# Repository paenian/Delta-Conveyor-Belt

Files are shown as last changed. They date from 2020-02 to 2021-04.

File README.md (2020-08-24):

## Delta-Conveyor-Belt
Adding a conveyor belt to my delta printer for part ejection.  The deltabot is somewhat described here: [Bertha](https://github.com/paenian/bertha), however it's been upgraded to the Delta Smart Effector as part of the conveyor belt addon.

Bertha Overview: https://www.youtube.com/watch?v=_Ud6TqBTL1Y

This is a follow-up to [Beltalowda](https://github.com/paenian/beltalowda),  which was styled as an upgraded Printrbelt.

## Status!
Bertha is quite reliable and functioned well printing face shields to help fight the COVID pandemic - check out her timelapse: https://www.youtube.com/watch?v=ywWMOnBR8Mk

## Expanding the Belt!

I've been expanding the belt system, however - there are versions for:
- [Kossel 3D printer](https://github.com/paenian/Delta-Conveyor-Belt/tree/master/kossel%20-%20240mm%20triangle) - this works well, but is small :-)
- [Prusa Mini](https://github.com/paenian/Delta-Conveyor-Belt/tree/master/prusa%20mini) - Working, more actively developing around this machine right now.

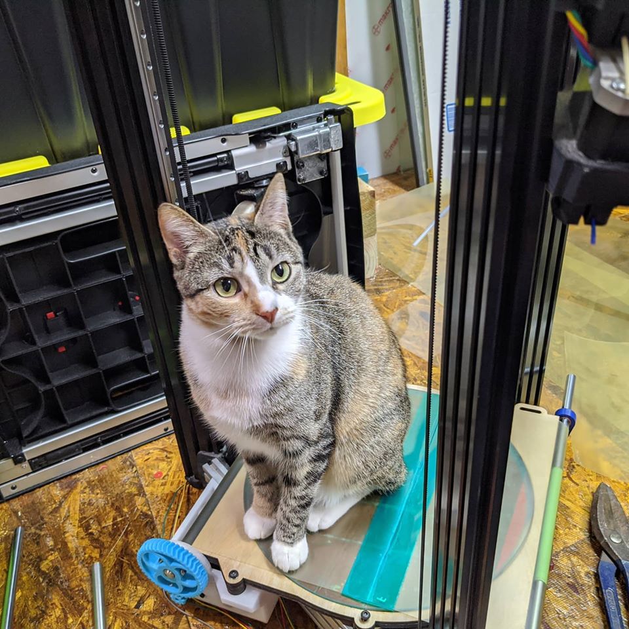
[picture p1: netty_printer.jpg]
Netty is the official mascot


### I've seen other belt printers... how is yours different?
I started working with stainless steel belts on Beltalowda (based off of the Printrbot's Printrbelt - the [White Knight](https://3ddistributed.com/white-knight-3d-printer/) uses steel as well) but was not super happy with it.  For one, the belt is inflexible - so it requires large rollers and very high force to stretch it out flat.  The other issue is heating the belt - as the belt material expands, it develops ripples in the surface ruining your print's bottom layer.  This is also an issue when the nozzle gets close to the bed - without excellent cooling, the bed will locally warp due to local heating from the nozzle and hot plastic.

To get around those, I experimented with thin, plastic belts - PEI, Kapton and Polyester (duralar).  They can be bent around a tiny radius, stretch minimally, and have managable thermal expansion.  To combat local heating, and help your print stick - heat the bed first!  To combat the warping that heating the bed gets you, I'm heating both sides of the bed - and rolling it to flatten it out when hot.  This has mitigated the problem enough that I've had successful prints, but plastics that warp (ABS) locally bend the belt to their will.  This can be partially solved with rafts, but given how well the thin belts are working, I thought I should release to the community and see what other solutions crop up.  I believe simply tuning the temperature and rolling profiles can lead to some improvement.

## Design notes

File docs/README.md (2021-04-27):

# Welcome to PrintShift!

This site was created using [**Docsify**](https://docsify.js.org), which is an open source documentation site generator, and imported in GitHub pages.

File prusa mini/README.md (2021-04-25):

#  Prusa Mini Conveyor Belt!

Status: Fully Functional!

Quick overview - this repo contains all the files I used to add a conveyor belt to my Prusa Mini.

## BELT MATERIAL
The current belt is made from .2mm thick Kapton, ordered from AliExpress and lasercut.  You can totally hand-cut it, but tracking of the belt is a bit of a pain.

The belt is designed to be easily replaced - other materials I have used:
 * .01" polyester film: Cuts easily, prints stick very well with hairspray.  This belt has higher thermal expansion, but with PLA or lower temps on the heater it works great, and is quite cheap.
  * https://www.mcmaster.com/8567K92/
  * Use hairspray to help prints stick.
 * .225mm Kapton: Hard to cut, especially by hand - recommend using a laser.  Low thermal expansion.  More expensive than the polyester.
  * https://www.aliexpress.com/item/4000699107361.html?spm=a2g0s.9042311.0.0.19534c4dqCLd9z
  * Use hairspray to help prints stick.
 * .005" ULTEM/PEI film: Prints stick well, but it's too flexible.  After ~10 hours printing, sheet sheared while printing.  It was under a lot of tension.  Gets expensive quick.
  * https://catalog.cshyde.com/item/films/ultem-pei-polyethermide-resin/36-5f
 * .01" ULTEM/PEI film: Same story as the .005; less flexible, of course, so prints warped less on it.  However, it did shear mid-print after maybe 100 hours of printing - it lasted longer, but split right in two.  My assumption is more due to fatigue from all the rolling.
  * https://catalog.cshyde.com/item/films/ultem-pei-polyethermide-resin/36-10f
  
 I have used thicker and stiffer belts, too - various stainless steels and conveyor materials, usually covering the belt itself in PET tape to get good adhesion and release.  However, these require larger, stronger rollers - so aren't compatible with the printers in this repository.

## CONTROL
The belt is controlled by a microswitch mounted on the top of the Z axis.  When the Z gets high enough and Y is forward enough, your parts scoot.  The nice part is no modification of the firmware is required - just some special start and end GCODE in your slicer.  I do take power for the motor from inside the Prusa Mini box for neatness - I like my printers as self-contained as possible.

The other modifications to the Prusa Mini involve raising the bed 4mm - so combined with the switch up top, you're losing about 15mm of usable Z axis.

Right now, the belt is 150mm in width - so your Y axis shrinks a bit when printing on the belt.  You can, however, still print using the entire bed - just put the metal build plate on top of the belt!  I plan to work on widening the belt, but for now I want the machine to be as rigid as possible.

## PARTS NEEDED
.2mm thick KAPTON film - 155mm by 425-430mm
 - Alternative bed material is PEI film or Dur-a-lar

5/16" diameter tool steel rod, for the rollers
5/16" ID EPDM rubber tubing, goes on the drive rod to grip and move the belt

V-156-1C25 microswitch to actuate the belt - https://smile.amazon.com/Cylewet-V-155-1C25-Switch-Arduino-CYT1081/dp/B075PTBML8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

24v, 30rpm , 6mm worm gear motor to drive the belt: https://smile.amazon.com/gp/product/B01N1JQLG4/ref=ppx_yo_dt_b_asin_title_o00_s00?ie=UTF8&psc=1

various screws and wires
10mm long M3 hex standoffs: https://www.mcmaster.com/94868A166/

##INSTALLATION
For all the printed parts, I used PETG with carbon-fiber embedded.  Not all need the strength, but I'd say the gears and the LM8UU clamps definitely benefit.

First dismantle the heated bed and set aside - then take the entire Y axis apart.  The belt needs to run flat, so first we replace the U-bolt clamps holding the LM8UUs on with printed clamps.
 - I used a chamfer drill to make countersink holes in the aluminum Y carriage, and used M3x16mm flat top screws.  Clearance is pretty tight on the electronics side.
 - Printed Part: lm8uu clamp.stl
While you're down here, remove all the hexagonal standoffs.  We need taller ones.

Replace the front three and back three hex standoffs with 10mm long ones - middle standoffs never get replaced.

Netty is the official mascot

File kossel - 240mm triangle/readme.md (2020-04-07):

Kossel Conveyor Belt!

These are all the STLs you need to throw a belt on the bottom of a Kossel 3D printer.

Parts Required:
 * (1)  200 by 213mm by 3mm borosilicate glass plate - a rectilinear prism, not round glass!
 * (1)  200mm silicone heater pad - should be ~2mm thick.  It's gotta be placed nice and central.
 * (1)  250mm 1/2" steel shaft - this is the idler
 * (1)  300mm 1/2" steel shaft - this is the drive roller
  * I bought this and cut it down: https://smile.amazon.com/gp/product/B08639C1MX/ref=ppx_yo_dt_b_asin_title_o00_s00?ie=UTF8&psc=1
 * (1)  200mm 1/2" EPDM rubber
  * https://www.mcmaster.com/4339t5
  * Ultra Weather resistand EPDM Foam Tube - 1/2" ID, 5/8" OD
 * (4)  1/2" Bronze Bushings
  * https://www.mcmaster.com/6338k572
  * Oil-Embedded Flanged Sleeve Bearing
  * 1/2" shaft, 5/8" housing ID, 1/2" long, 1/16" flange thickness
 * (2) Nema 17 motors, 38, 40 or 42mm long
  * needs a decent amount of torque, but it's got a big mechanical advantage

Fasteners:
 * (12) M5 T-nut - attach the motor drive brackets & idler brackets
 * (18) M5 screw 10mm - attach the motor drive breackets & idler brackets, attach belt drive gear to the shaft
 * (2)  M5 screw 35mm - attach the belt tensioner arm to its bracket
 * (2)  M5 screw 40mm fully threaded - tension the belt
 * (10) M3 screw 10mm - attach the motors & the motor drive gears
 * (2)  M3 hex nut - attach the motor drive gears
 * (2)  M5 lock nuts - attach the belt tensioner arm to its bracket
 * (8)  M5 hex nuts - tension the belt, attach belt drive gear to the shaft

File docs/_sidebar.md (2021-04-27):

<!-- docs/_sidebar.md -->

* [About the Project](./)

* [Tutorials](./tutorials/index.md)
  * [Build PrintShift!](./tutorials/BuildPrintShift.md)
  * [Make a looped conveyor Belt](./tutorials/ContinuousBelt.md)

* [Become a Patron](https://www.patreon.com/PrintShift)

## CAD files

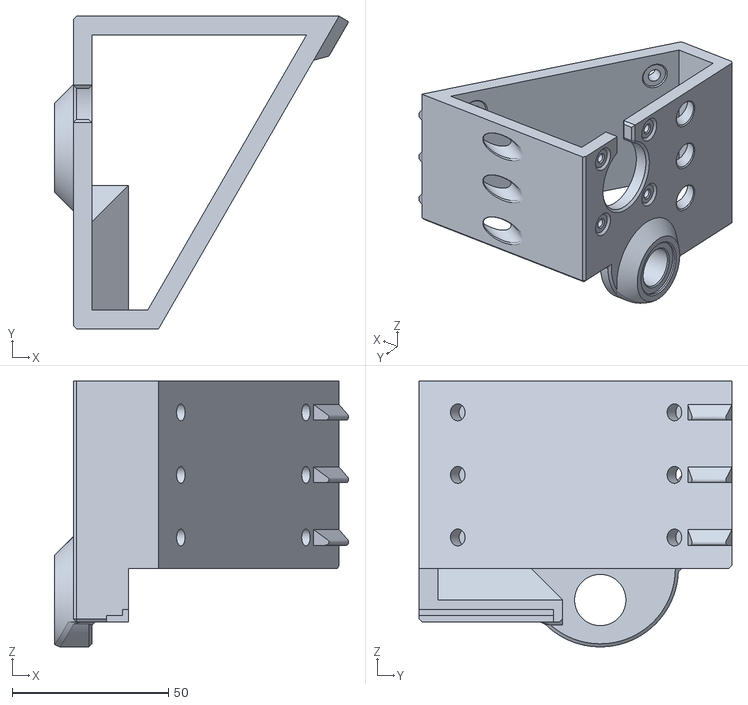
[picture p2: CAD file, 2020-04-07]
kossel - 240mm triangle/belt motor assembly(Mirror).stl
94.0 x 100.0 x 85.0

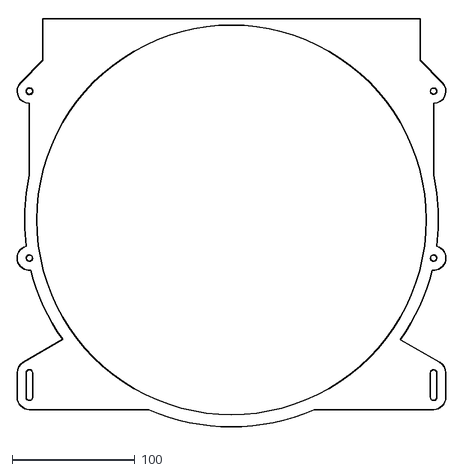
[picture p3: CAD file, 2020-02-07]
bertha top bed - incomplete.dxf
351.6 x 339.8

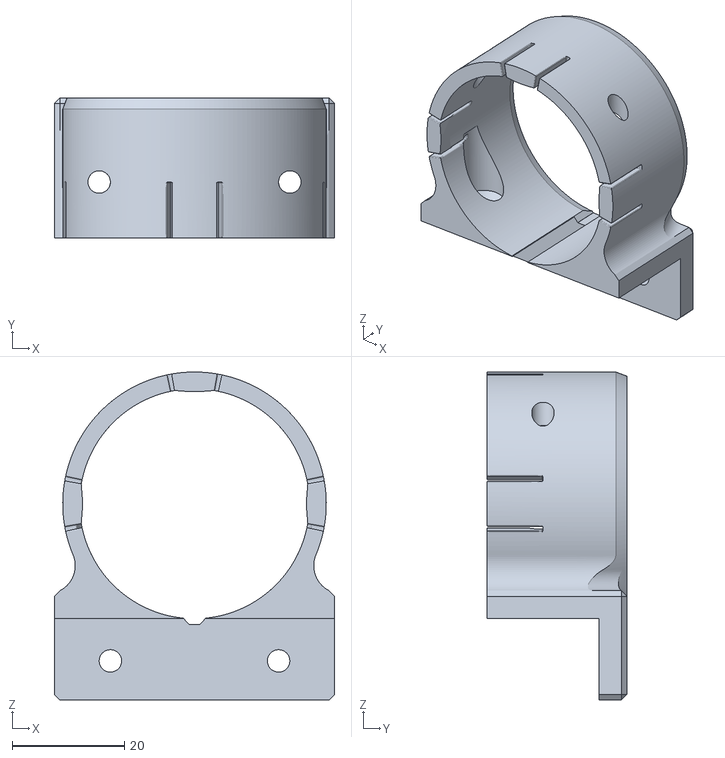
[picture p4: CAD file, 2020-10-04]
gopro bolus mount.stl
50.0 x 25.0 x 58.5

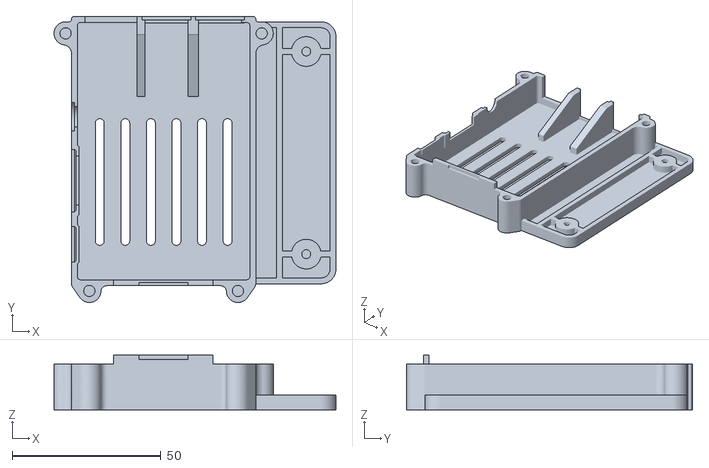
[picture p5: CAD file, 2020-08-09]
kossel - 240mm triangle/ancillary STLs/Raspberry_Pi_3_Case_-_Top.stl
94.9 x 96.2 x 18.5

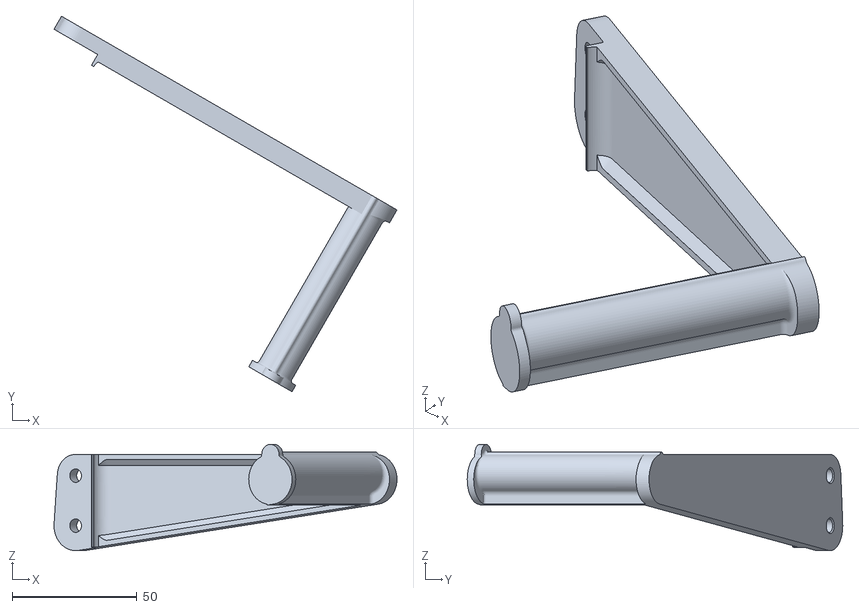
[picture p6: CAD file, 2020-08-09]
kossel - 240mm triangle/spool holder.stl
137.2 x 150.2 x 42.5

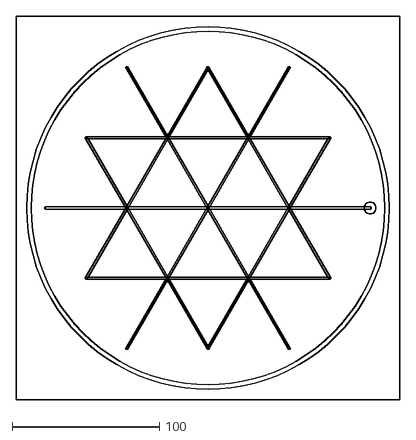
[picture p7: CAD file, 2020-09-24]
kossel linear plus/combined.dxf
260.0 x 260.0

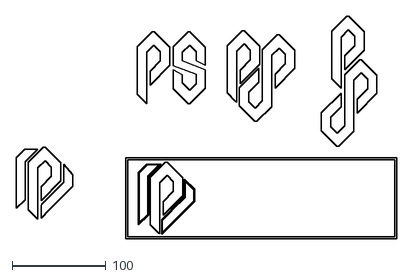
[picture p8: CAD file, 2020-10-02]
logos/printshift.dxf
405.9 x 237.1

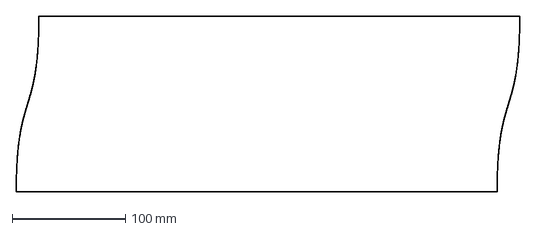
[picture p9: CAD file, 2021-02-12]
prusa mini/bed lasercutting/flat_angle-425x155.dxf
445.0 x 155.0 mm

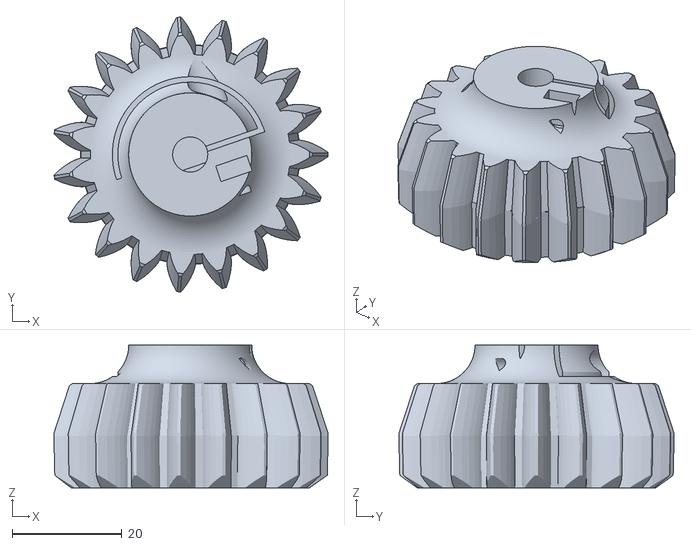
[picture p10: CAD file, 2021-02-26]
prusa mini/ejector 2.0/motor_gear.stl
49.9 x 50.1 x 26.0

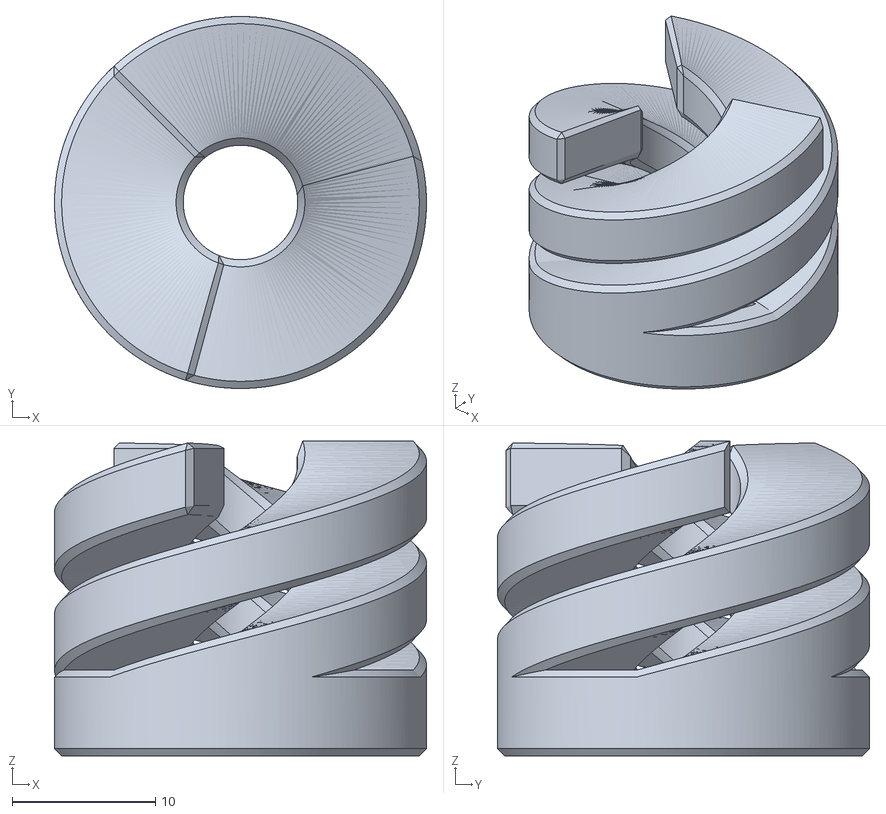
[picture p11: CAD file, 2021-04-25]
prusa mini/ejector 3.0/failed coupler iterations/spring coupler.stl
26.0 x 26.0 x 22.0

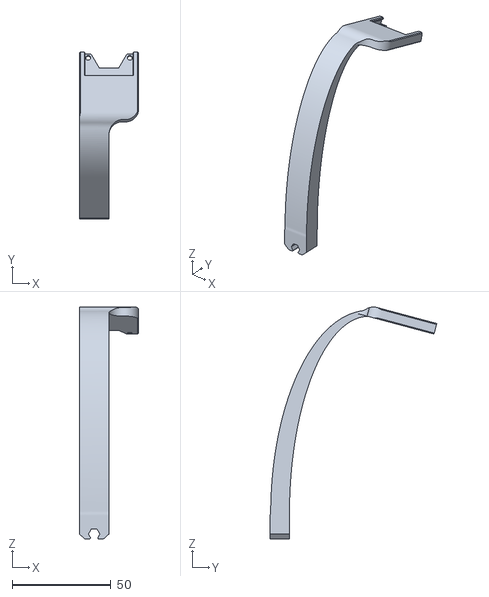
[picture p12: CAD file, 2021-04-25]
prusa mini/ejector 3.0/rear camera mount.stl
30.0 x 84.2 x 117.2

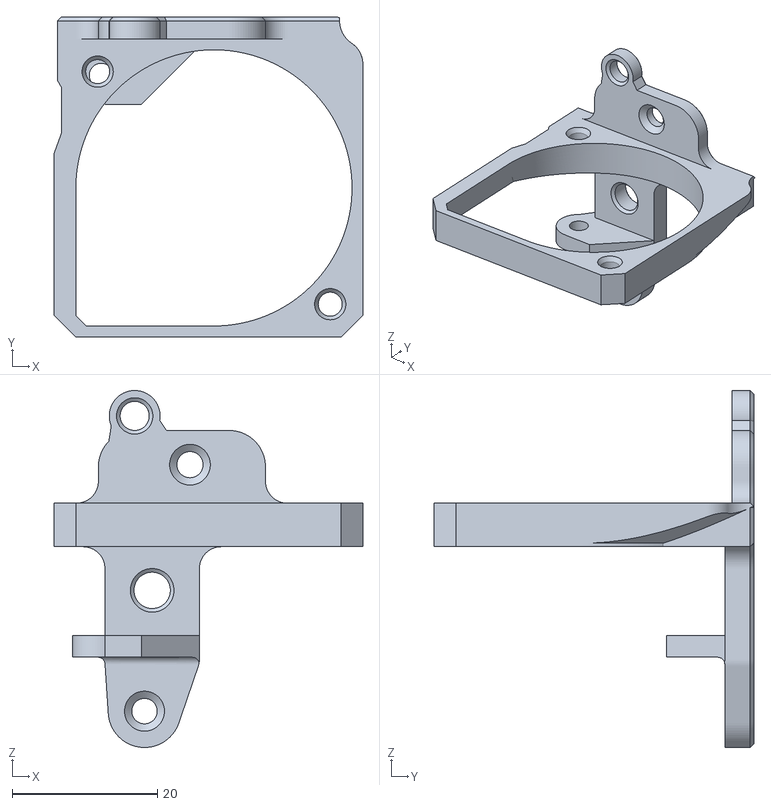
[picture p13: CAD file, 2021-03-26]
prusa mini/experimental parts/orbiter-fan-spacer.stl
42.5 x 44.0 x 49.1

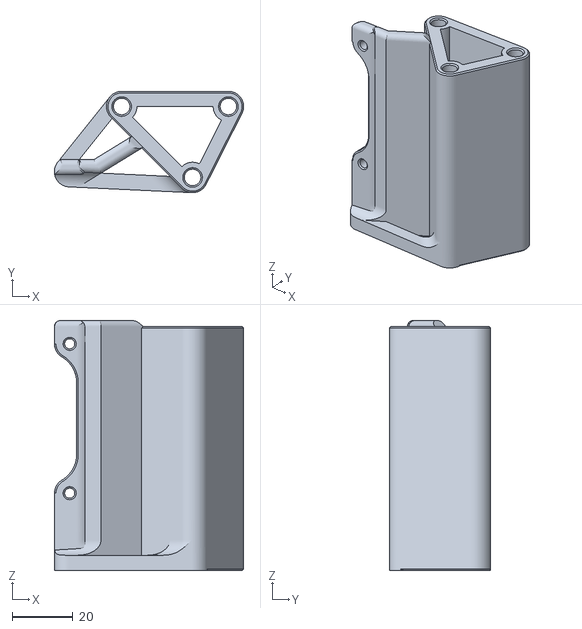
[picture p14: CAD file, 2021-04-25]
prusa mini/motor plate standoff-80mm.stl
62.1 x 33.2 x 82.0

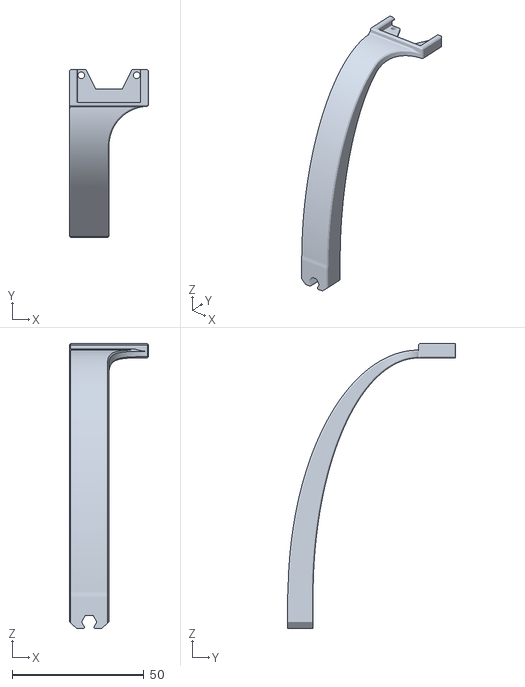
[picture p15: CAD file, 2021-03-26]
prusa mini/raspi/rear camera mount.stl
30.0 x 63.8 x 108.0

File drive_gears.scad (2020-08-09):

include <configuration.scad>
use <herringbone_gears.scad>
use <functions.scad>

//gear variables

motor_shaft_rad = 5/2+.2;
//drive_shaft_rad = 12/2+.2;

drive_shaft_rad = 25.4/2/2+.2;

small_teeth = 9;
big_teeth = 47;
gear_thick = 13;
distance_between_axles = 50;

circular_pitch = 360*distance_between_axles/(small_teeth+big_teeth);

part = 2;

if(part == 1){
   mirror([0,0,1]) motor_drive_gear();
}

if(part == 2){
    mirror([0,0,1]) roller_drive_gear();
}

if(part == 100){
    assembled();
}

module assembled(){
    difference(){
        union(){
            mirror([0,0,1]) motor_drive_gear();
            mirror([0,0,1]) roller_drive_gear();
        }
        translate([0,100,0]) cube([200,200,200], center=true);
    }
}

module motor_drive_gear(){
    translate([distance_between_axles+1,0,0]) gear1(gear1_teeth = small_teeth, circular_pitch=circular_pitch, gear_height=gear_thick);
}

module roller_drive_gear(wall = 3){
    %motor_drive_gear();
    
    radius = gear_radius(big_teeth, circular_pitch);
    outer_radius = gear_outer_radius(big_teeth, circular_pitch);
    
    gear_chamfer_radius = (outer_radius - radius) / tan(45);
    
    lift = gear_thick+1;
    
    difference(){
        union(){
            //gear
            chamfered_herring_gear(height=gear_thick, number_of_teeth=big_teeth, circular_pitch=circular_pitch, teeth_twist=-1);
        }
        
        //the shaft
        translate([0,0,-.5]) cylinder(r=drive_shaft_rad, h=gear_thick+1);
        
        //gotta hold it on somehow
        
                //screws and nuts to mount to the shaft
                translate([0,0,gear_thick/2]) for(i=[0:120:359]) rotate([0,0,i]) {
                    rotate([90,0,0]) cap_cylinder(r=m5_rad, h=25);
                    rotate([90,0,0]) cap_cylinder(r=m3_rad+.25, h=75);
                    //nut trap
                    rotate([90,0,0]) cylinder(r2=8.135/cos(180/6)/2,r1=8.135/cos(180/6)/2+.3, h=10, $fn=6);
                }
                
        translate([0,0,gear_thick/2]) difference(){
            //hollow most of the gear
            cylinder(r=outer_radius-6.1, h=gear_thick+1, center=true);
            
            //but leave the middle for attachments
            difference(){
                cylinder(r=drive_shaft_rad+7, h=gear_thick+2, center=true);
            }
            
            //biohazard!
            for(i=[30:120:359]) rotate([0,0,i]) difference(){
                translate([(outer_radius-3.5)/2,0,0]) cylinder(r=(outer_radius-5)/2,h=gear_thick, center=true);
                translate([(outer_radius-4+8-2.5)/2,0,0]) cylinder(r=(outer_radius-5-8)/2,h=gear_thick+1, center=true);
            }
        }
    }
}

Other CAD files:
kossel - 240mm triangle/belt motor assembly.stl
kossel - 240mm triangle/ancillary STLs/HVplate.stl
kossel - 240mm triangle/motor_drive_gear.stl
kossel linear plus/triangles.dxf
kossel - 240mm triangle/drive_gears.scad
prusa mini/configuration.scad
prusa mini/drive_gears.scad
bed bottom plate.dxf
bed plates + spacers.dxf
bed top plate.dxf
bertha drive bracket.stl
bertha top bed.dxf
bump carriage.stl
drive bracket.stl
drive_gear.stl
extra bumper.stl
herringbone_gears.scad
kossel - 240mm triangle/ancillary STLs/LVplate.stl
kossel - 240mm triangle/ancillary STLs/Raspberry_Pi_3_Case_-_Bottom.stl
kossel - 240mm triangle/ancillary STLs/psu_bracket.stl
kossel - 240mm triangle/ancillary STLs/pwr_shield4.stl
kossel - 240mm triangle/bltouch mount.stl
kossel - 240mm triangle/electronics side mirrored.stl
kossel - 240mm triangle/electronics side.stl
kossel - 240mm triangle/electronics top.stl
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

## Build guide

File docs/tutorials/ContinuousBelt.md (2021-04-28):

---
title: "Making a Continuous Belt from sheet stock"
excerpt_separator: "<!--more-->"
categories:
  - PrintShift
tags:
  - Conveyor Belt
  - Continuous
  - Tutorial
  - Build
---

# Making a Continuous Belt.

This page details how to build a continuous loop conveyor belt from a flat sheet of material.   It will enable you to test out any material on your PrintShift or other belt-based printer, and is widely applicable for joining strips of material.  

<!--more-->

## Materials Needed
1. Belt Joining Tape.  What sort of tape!?  Three things to consider are:
   * Tape Material
   * Tape Thickness
   * Tape Adhesive
2. Belt.  Again, what sort?
   * You need a strip ~20mm longer than your final loop size, cut to the correct width.
3. Painter's Tape
   * This is used to hold the belt in place while assembling, and discarded afterwards.  1" wide is fine; pictured below use 2" wide.

## Tools Needed
1. Block of wood to cut on.
   * If your printer can't slide a continuous belt on, a thin piece of HDPE or similar (cutting mat) is recommended to protect your bed.
2. Sharp knife capable of cutting your belt.
3. Light.  Do not attempt in darkness.

## Procedure
1. Place belt outside-down on your work surface.
2. Place block of wood on top.
3. Form the belt into an overlapping loop - lining up the straightest edge with itself.
4. Tape the belt into a loop
5. Thoroughly tape the belt to the wood cutting block on either side of the joining tape line.
6. Cut through BOTH layers of the belt.
   * cutting at a slight angle will help maintain belt tension over the seam.
7. Remove the ends of the belt carefully - the goal is not to disturb the joint.
8. Join the belt ends with your Belt Joining Tape.
9. Woo it's a belt!  Carefully remove the blue tape and install it on your printer.

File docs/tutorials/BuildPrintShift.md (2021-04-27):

This page will be a Markdown-based tutorial walking through how to build PrintShift.

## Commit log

2019-11-17 Initial commit of the business parts!
    Designed without the machine on hand, so there'll likely be a few
    updates once she comes in, but I did leave some play for the drive
    brackets.
    Bed plates need to be updated with holes for the wires.
    Need some standoffst for the bed plates.
    The conveyor belt axles are situated 10mm above the rails, and are
    12mm shafts - so there's 4mm clearance. Bed should finish 16mm
    above the rails, so would need 10mm standoffs to attach the bed
    plates.
    I'll work on a BOM in a bit... kinda wanna eyeball the bits first.
    [bed bottom plate.dxf, bed top plate.dxf, configuration.scad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]
2019-11-17 Adding the Fusion 360 file
    [kossel conveyor belt.f3d]
2020-02-07 Updated parts for Bertha
    [bertha drive bracket.stl, bertha top bed - incomplete.dxf]
2020-02-07 Added lasercut files
    I edited them in place to add a straight edge on the bed plates -
    thinking that gives the belt the best chance of maintaining
    flatness over the circular build surface.
    [bertha top bed.dxf]
2020-03-01 updated parts for the large deltabot
    [bertha drive bracket.stl, bump carriage.stl, drive_gears.scad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]
2020-04-07 Added a bunch of parts for a 240mm Kossel version.
    [belt motor assembly(Mirror).stl, belt motor assembly.stl, bltouch mount.stl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]
2020-04-07 Added some Marlin Firmware
    [Configuration.h, Configuration_adv.h]
2020-08-09 Adding all the Prusa Mini files in here.
    [3030 m3 tnut.stl, 3030-dropin-tee-m3.stl, Configuration.h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]
2020-08-09 Slight cleanup.
    [3030-dropin-tee-m3.stl, microswitch spacer.stl, raspi3b-mk3s-case-bottom.stl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]
2020-08-16 Updated raspi cases.
    [raspi3b-mk3s-case-bottom.stl, raspi3b-mk3s-case-top-camera.stl, raspi_case_bottom.stl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]
2020-09-24 Adding bed stuff for a slightly larger kossel
    [combined.dxf, o-ring groove.dxf, triangles.dxf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]
2020-10-02 Added logos, regenerated parts
    Significant changes to
    * motor mount for more rigidity
    * tensioners for better retention/strength
    [MINI-heatbed-cable-cover-bottom.stl, belt motor mount.stl, belt_gear.stl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]
2020-10-04 Added a shelf-mount for my gopro
    More vids coming soon!
    [gopro bolus mount.stl]
2020-10-14 Updated gears, lm8uu clamp
    Gears are now beefier and clamp more strongly
    lm8uu clamp can slip between the rails - quicker to install.
    lm8uu clamp now uses square nuts to match the gears - lower part
    count.
    [bed center support.stl, belt_gear.stl, drive_gears.scad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]
2020-10-20 Updated the center support - 9.5mm tall.
    [bed center support.stl, small_base_light.stl]
2020-10-22 New belt!
    Trying a design with a slightly wider interface, near rectilinear - less sinusoidal, this is all ellipses.
    [belt_425mm.dxf]
2020-10-22 belt lasercut files
    Figure the more puzzle-like joint should be much easier to align.
2020-11-02 Updated belt - the tab/slot was too long
    Tape didn't hold up - very much tangling of the belt. This one
    extends half the distance.
    Belt is overall 155mm wide, 425mm long - any end shape should be
    fine. I'm thinking of angling the ends to make sure there's no
    force, but I like the symmetrical better for now.
    [belt_425mm.dxf]
2020-11-02 Lasercut files for the belt
2020-11-18 Updated the gears
    Also added experimental parts - raising the bed 2mm to provide
    clearance, while not actually guiding the belt underside.
    Seems to be more durable, in that the bed tape doesn't catch and
    tear, while providing pretty similar flatness.
    [drive_gears.scad, front spool holder.stl, lifted belt shaft mount - fixed bushing.stl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]
2020-12-28 Working on a new motor mount
    mount the motor to the 3030 under the bed, instead of in front.
    [drive_gears.scad, motor_gear.stl, rear motor clamp.stl]
2020-12-28 Turned around the wrong gear...
    So yeah, new plan is to drive the belt from the back. It'll still
    eject from the same position, just moving the motor and the belt
    gear to the rear-side.
    [belt_gear.stl, drive_gears.scad]
2020-12-29 it'd probably be best if the bed clears the gears...
    [belt_gear.stl, drive_gears.scad, rear motor clamp.stl]
2021-02-12 Adding version 2.0 and... tree...
    Yep. Version 2.0 increases force, which is great. But I'm worried
    about bending the mini's bed... and had a cool idea for a better belt
    motor mounting, so I'm working on that now.
    I'd recommend skipping 2.0 - 3.0 will be out soon.
    Paul
    [bed center support v2.f3d, belt v2.f3d, belt_gear.stl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]
2021-02-12 Adding lasercut profiles for the bed
    need to cut more kapton
    [chevron-425x155.dxf, flat_angle-425x155.dxf, rounded_notch-425x155.dxf]
2021-02-12 Adding lasercut file
2021-02-19 Adding version 3.0 ejector parts
    The coupler is still a work i progress, but everything else is a go.
    Coupler works... most of the time
    [5mm shaft side.stl, 8mm shaft side.stl, Pi_4_Case_40mm_fan_top v3.stl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]
2021-02-26 Adding all the 3.0 ejector parts!
    [5mm shaft side.stl, 8mm shaft side.stl, Body37.stl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]
2021-03-26 Added the orbiter extruder mount
    [orbiter-fan-spacer.stl, rear camera mount.stl, rear motor plate.stl]
2021-04-15 updated bed size
2021-04-25 Multiple updates!
    Updated the rear motor plate for larger 8mm flanged bearings.
    Updated the rear camera mount - just a bit larger and angled down
    towards the bed.
    Updated the start and end gcodes - it'd been a while
    Added a Pi 3 case for the rear mount system
    Experimental:
    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
    [motor plate standoff-80mm.stl, pi_3_case_bottom.stl, pi_3_case_top.stl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]
2021-04-25 Adding the latest Fusion 360 assembly
    For those who want to improve on the design!
    Thanks,
    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
